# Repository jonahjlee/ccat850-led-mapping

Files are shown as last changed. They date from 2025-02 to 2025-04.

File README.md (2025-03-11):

# ccat850-led-mapping
CAD files for CCAT 850GHz LED mapping array PCB &amp; peripherals

This project contains various cad files relating to hardware required to perform LED mapping for CCAT's 850GHz module.
This project includes the following directories:
- ``led_mapper_850``
  - The defining the PCB for one rhombus of the LED mapper array. Contains the KiCAD project and some Python programs used to automate the LED/via/track layout.
- ``multiplexer`` - NO LONGER USED
  - The cable splitter used between the Arduino shield and the mapper array. Splits the inputs into 13 parallel 24-pin connectors. Since the PCB has been updated to use a single connector, this is no longer relevant to the project.
- ``collimator``
  - SOLIDWORKS CAD files for the collimator, which mounts to the array and nests each LED such that light is funneled one-to-one with the feedhorns. The old collimator CAD model can be found in [this onshape project](https://cad.onshape.com/documents/4a9874995d3b4039a34f4491/w/a61d1c1f9ee3ea8193c6d7eb/e/afbea4677e4648f6492246a2).

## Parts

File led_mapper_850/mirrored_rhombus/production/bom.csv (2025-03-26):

Designator | Footprint | Quantity | Value | LCSC Part #
D1, D10, D100, D1000, D1001, D1002, D1003, D1004, D1005, D1006, D1007, D1008, D1009, D101, D1010, D1011, D1012, D1013, D1014, D1015, D1016, D1017, D1018, D1019, D102, D1020, D1021, D1022, D1023, D1024, D1025, D1026, D1027, D1028, D1029, D103, D1030, D1031, D1032, D1033, D1034, D1035, D1036, D1037, D1038, D1039, D104, D1040, D1041, D1042, D1043, D1044, D1045, D1046, D1047, D1048, D1049, D105, D1050, D1051, D1052, D1053, D1054, D1055, D1056, D1057, D1058, D1059, D106, D1060, D1061, D1062, D1063, D1064, D1065, D1066, D1067, D1068, D1069, D107, D1070, D1071, D1072, D1073, D1074, D1075, D1076, D1077, D1078, D1079, D108, D1080, D1081, D1082, D1083, D1084, D1085, D1086, D1087, D1088, D1089, D109, D1090, D1091, D1092, D1093, D1094, D1095, D1096, D1097, D1098, D1099, D11, D110, D1100, D1101, D1102, D1103, D1104, D1105, D1106, D1107, D1108, D1109, D111, D1110, D1111, D1112, D1113, D1114, D1115, D1116, D1117, D1118, D1119, D112, D1120, D1121, D1122, D1123, D1124, D1125, D1126, D1127, D1128, D1129, D113, D1130, D1131, D1132, D1133, D1134, D1135, D1136, D1137, D1138, D1139, D114, D1140, D1141, D1142, D1143, D1144, D1145, D1146, D1147, D1148, D1149, D115, D1150, D1151, D1152, D1153, D1154, D1155, D1156, D1157, D1158, D1159, D116, D1160, D1161, D1162, D1163, D1164, D1165, D1166, D1167, D1168, D1169, D117, D1170, D1171, D1172, D1173, D1174, D1175, D1176, D1177, D1178 | 0201 | 200 | LED | C3646923
D1179, D118, D1180, D1181, D1182, D1183, D1184, D1185, D1186, D1187, D1188, D1189, D119, D1190, D1191, D1192, D1193, D1194, D1195, D1196, D1197, D1198, D1199, D12, D120, D1200, D1201, D1202, D1203, D1204, D1205, D1206, D1207, D1208, D1209, D121, D1210, D1211, D1212, D1213, D1214, D1215, D1216, D1217, D1218, D1219, D122, D1220, D1221, D1222, D1223, D1224, D1225, D1226, D1227, D1228, D1229, D123, D1230, D1231, D1232, D1233, D1234, D1235, D1236, D1237, D1238, D1239, D124, D1240, D1241, D1242, D1243, D1244, D1245, D1246, D1247, D1248, D1249, D125, D1250, D1251, D1252, D1253, D1254, D1255, D1256, D1257, D1258, D1259, D126, D1260, D1261, D1262, D1263, D1264, D1265, D1266, D1267, D1268, D1269, D127, D1270, D1271, D1272, D1273, D1274, D1275, D1276, D1277, D1278, D1279, D128, D1280, D1281, D1282, D1283, D1284, D1285, D1286, D1287, D1288, D1289, D129, D1290, D1291, D1292, D1293, D1294, D1295, D1296, D1297, D1298, D1299, D13, D130, D1300, D1301, D1302, D1303, D1304, D1305, D1306, D1307, D1308, D1309, D131, D1310, D1311, D1312, D1313, D1314, D1315, D1316, D1317, D1318, D1319, D132, D1320, D1321, D1322, D1323, D1324, D1325, D1326, D1327, D1328, D1329, D133, D1330, D1331, D1332, D1333, D1334, D1335, D1336, D1337, D1338, D1339, D134, D1340, D1341, D1342, D1343, D1344, D1345, D1346, D1347, D1348, D1349, D135, D1350, D1351, D1352, D1353, D1354, D1355, D1356, D1357, D1358 | 0201 | 200 | LED | C3646923
D1359, D136, D1360, D1361, D1362, D1363, D1364, D1365, D1366, D1367, D1368, D1369, D137, D1370, D1371, D1372, D1373, D1374, D1375, D1376, D1377, D1378, D1379, D138, D1380, D1381, D1382, D1383, D1384, D1385, D1386, D1387, D1388, D1389, D139, D1390, D1391, D1392, D1393, D1394, D1395, D1396, D1397, D1398, D1399, D14, D140, D1400, D1401, D1402, D1403, D1404, D1405, D1406, D1407, D1408, D1409, D141, D1410, D1411, D1412, D1413, D1414, D1415, D1416, D1417, D1418, D1419, D142, D1420, D1421, D1422, D1423, D1424, D1425, D1426, D1427, D1428, D1429, D143, D1430, D1431, D1432, D1433, D1434, D1435, D1436, D1437, D1438, D1439, D144, D1440, D1441, D1442, D1443, D1444, D1445, D1446, D1447, D1448, D1449, D145, D1450, D1451, D1452, D1453, D1454, D1455, D1456, D1457, D1458, D1459, D146, D1460, D1461, D1462, D1463, D1464, D1465, D1466, D1467, D1468, D1469, D147, D1470, D1471, D1472, D1473, D1474, D1475, D1476, D1477, D1478, D1479, D148, D1480, D1481, D1482, D1483, D1484, D1485, D1486, D1487, D1488, D1489, D149, D1490, D1491, D1492, D1493, D1494, D1495, D1496, D1497, D1498, D1499, D15, D150, D1500, D1501, D1502, D1503, D1504, D1505, D1506, D1507, D1508, D1509, D151, D1510, D1511, D1512, D1513, D1514, D1515, D1516, D1517, D1518, D1519, D152, D1520, D1521, D1522, D1523, D1524, D1525, D1526, D1527, D1528, D1529, D153, D1530, D1531, D1532, D1533, D1534, D1535, D1536, D1537, D1538 | 0201 | 200 | LED | C3646923
D1539, D154, D1540, D1541, D1542, D1543, D1544, D1545, D1546, D1547, D1548, D1549, D155, D1550, D1551, D1552, D1553, D1554, D1555, D1556, D1557, D1558, D1559, D156, D1560, D1561, D1562, D1563, D1564, D1565, D1566, D1567, D1568, D1569, D157, D1570, D1571, D1572, D1573, D1574, D1575, D1576, D1577, D1578, D1579, D158, D1580, D1581, D1582, D1583, D1584, D1585, D1586, D1587, D1588, D1589, D159, D1590, D1591, D1592, D1593, D1594, D1595, D1596, D1597, D1598, D1599, D16, D160, D1600, D1601, D1602, D1603, D1604, D1605, D1606, D1607, D1608, D1609, D161, D1610, D1611, D1612, D1613, D1614, D1615, D1616, D1617, D1618, D1619, D162, D1620, D1621, D1622, D1623, D1624, D1625, D1626, D1627, D1628, D1629, D163, D1630, D1631, D1632, D1633, D1634, D1635, D1636, D1637, D1638, D1639, D164, D1640, D1641, D1642, D1643, D1644, D1645, D1646, D1647, D1648, D1649, D165, D1650, D1651, D1652, D1653, D1654, D1655, D1656, D1657, D1658, D1659, D166, D1660, D1661, D1662, D1663, D1664, D1665, D1666, D1667, D1668, D1669, D167, D1670, D1671, D1672, D1673, D1674, D1675, D1676, D1677, D1678, D1679, D168, D1680, D1681, D1682, D1683, D1684, D1685, D1686, D1687, D1688, D1689, D169, D1690, D1691, D1692, D1693, D1694, D1695, D1696, D1697, D1698, D1699, D17, D170, D1700, D1701, D1702, D1703, D1704, D1705, D1706, D1707, D1708, D1709, D171, D1710, D1711, D1712, D1713, D1714, D1715, D1716, D1717, D1718 | 0201 | 200 | LED | C3646923
D1719, D172, D1720, D1721, D1722, D1723, D1724, D1725, D1726, D1727, D1728, D1729, D173, D1730, D1731, D1732, D1733, D1734, D1735, D1736, D1737, D1738, D1739, D174, D1740, D1741, D1742, D1743, D1744, D1745, D1746, D1747, D1748, D1749, D175, D1750, D1751, D1752, D1753, D1754, D1755, D1756, D1757, D1758, D1759, D176, D1760, D1761, D1762, D1763, D1764, D1765, D1766, D1767, D1768, D1769, D177, D1770, D1771, D1772, D1773, D1774, D1775, D1776, D1777, D1778, D1779, D178, D1780, D1781, D1782, D1783, D1784, D1785, D1786, D1787, D1788, D1789, D179, D1790, D1791, D1792, D1793, D1794, D1795, D1796, D1797, D1798, D1799, D18, D180, D1800, D1801, D1802, D1803, D1804, D1805, D1806, D1807, D1808, D1809, D181, D1810, D1811, D1812, D1813, D1814, D1815, D1816, D1817, D1818, D1819, D182, D1820, D1821, D1822, D1823, D1824, D1825, D1826, D1827, D1828, D1829, D183, D1830, D1831, D1832, D1833, D1834, D1835, D1836, D1837, D1838, D1839, D184, D1840, D1841, D1842, D1843, D1844, D1845, D1846, D1847, D1848, D1849, D185, D1850, D1851, D1852, D1853, D1854, D1855, D1856, D1857, D1858, D1859, D186, D1860, D1861, D1862, D1863, D1864, D1865, D1866, D1867, D1868, D1869, D187, D1870, D1871, D1872, D1873, D1874, D1875, D1876, D1877, D1878, D1879, D188, D1880, D1881, D1882, D1883, D1884, D1885, D1886, D1887, D1888, D1889, D189, D1890, D1891, D1892, D1893, D1894, D1895, D1896, D1897, D1898, D1899 | 0201 | 200 | LED | C3646923
D19, D190, D1900, D1901, D1902, D1903, D1904, D1905, D1906, D1907, D1908, D1909, D191, D1910, D1911, D1912, D1913, D1914, D1915, D1916, D1917, D1918, D1919, D192, D1920, D1921, D1922, D1923, D1924, D1925, D1926, D1927, D1928, D1929, D193, D1930, D1931, D1932, D1933, D1934, D1935, D1936, D1937, D1938, D1939, D194, D1940, D1941, D1942, D1943, D1944, D1945, D1946, D1947, D1948, D1949, D195, D1950, D1951, D1952, D1953, D1954, D1955, D1956, D1957, D1958, D1959, D196, D1960, D1961, D1962, D1963, D1964, D1965, D1966, D1967, D1968, D1969, D197, D1970, D1971, D1972, D1973, D1974, D1975, D1976, D1977, D1978, D1979, D198, D1980, D1981, D1982, D1983, D1984, D1985, D1986, D1987, D1988, D1989, D199, D1990, D1991, D1992, D1993, D1994, D1995, D1996, D1997, D1998, D1999, D2, D20, D200, D2000, D2001, D2002, D2003, D2004, D2005, D2006, D2007, D2008, D2009, D201, D2010, D2011, D2012, D2013, D2014, D2015, D2016, D2017, D2018, D2019, D202, D2020, D2021, D2022, D2023, D2024, D2025, D2026, D2027, D2028, D2029, D203, D2030, D2031, D2032, D2033, D2034, D2035, D2036, D2037, D2038, D2039, D204, D2040, D2041, D2042, D2043, D2044, D2045, D2046, D2047, D2048, D2049, D205, D2050, D2051, D2052, D2053, D2054, D2055, D2056, D2057, D2058, D2059, D206, D2060, D2061, D2062, D2063, D2064, D2065, D2066, D2067, D2068, D2069, D207, D2070, D2071, D2072, D2073, D2074, D2075, D2076, D2077, D2078 | 0201 | 200 | LED | C3646923
D2079, D208, D2080, D2081, D2082, D2083, D2084, D2085, D2086, D2087, D2088, D2089, D209, D2090, D2091, D2092, D2093, D2094, D2095, D2096, D2097, D2098, D2099, D21, D210, D2100, D2101, D2102, D2103, D2104, D2105, D2106, D2107, D2108, D2109, D211, D2110, D2111, D2112, D2113, D2114, D2115, D2116, D212, D213, D214, D215, D216, D217, D218, D219, D22, D220, D221, D222, D223, D224, D225, D226, D227, D228, D229, D23, D230, D231, D232, D233, D234, D235, D236, D237, D238, D239, D24, D240, D241, D242, D243, D244, D245, D246, D247, D248, D249, D25, D250, D251, D252, D253, D254, D255, D256, D257, D258, D259, D26, D260, D261, D262, D263, D264, D265, D266, D267, D268, D269, D27, D270, D271, D272, D273, D274, D275, D276, D277, D278, D279, D28, D280, D281, D282, D283, D284, D285, D286, D287, D288, D289, D29, D290, D291, D292, D293, D294, D295, D296, D297, D298, D299, D3, D30, D300, D301, D302, D303, D304, D305, D306, D307, D308, D309, D31, D310, D311, D312, D313, D314, D315, D316, D317, D318, D319, D32, D320, D321, D322, D323, D324, D325, D326, D327, D328, D329, D33, D330, D331, D332, D333, D334, D335, D336, D337, D338, D339, D34, D340, D341, D342, D343, D344, D345, D346, D347, D348, D349, D35, D350, D351, D352, D353 | 0201 | 200 | LED | C3646923
D354, D355, D356, D357, D358, D359, D36, D360, D361, D362, D363, D364, D365, D366, D367, D368, D369, D37, D370, D371, D372, D373, D374, D375, D376, D377, D378, D379, D38, D380, D381, D382, D383, D384, D385, D386, D387, D388, D389, D39, D390, D391, D392, D393, D394, D395, D396, D397, D398, D399, D4, D40, D400, D401, D402, D403, D404, D405, D406, D407, D408, D409, D41, D410, D411, D412, D413, D414, D415, D416, D417, D418, D419, D42, D420, D421, D422, D423, D424, D425, D426, D427, D428, D429, D43, D430, D431, D432, D433, D434, D435, D436, D437, D438, D439, D44, D440, D441, D442, D443, D444, D445, D446, D447, D448, D449, D45, D450, D451, D452, D453, D454, D455, D456, D457, D458, D459, D46, D460, D461, D462, D463, D464, D465, D466, D467, D468, D469, D47, D470, D471, D472, D473, D474, D475, D476, D477, D478, D479, D48, D480, D481, D482, D483, D484, D485, D486, D487, D488, D489, D49, D490, D491, D492, D493, D494, D495, D496, D497, D498, D499, D5, D50, D500, D501, D502, D503, D504, D505, D506, D507, D508, D509, D51, D510, D511, D512, D513, D514, D515, D516, D517, D518, D519, D52, D520, D521, D522, D523, D524, D525, D526, D527, D528, D529, D53, D530, D531, D532, D533 | 0201 | 200 | LED | C3646923
D534, D535, D536, D537, D538, D539, D54, D540, D541, D542, D543, D544, D545, D546, D547, D548, D549, D55, D550, D551, D552, D553, D554, D555, D556, D557, D558, D559, D56, D560, D561, D562, D563, D564, D565, D566, D567, D568, D569, D57, D570, D571, D572, D573, D574, D575, D576, D577, D578, D579, D58, D580, D581, D582, D583, D584, D585, D586, D587, D588, D589, D59, D590, D591, D592, D593, D594, D595, D596, D597, D598, D599, D6, D60, D600, D601, D602, D603, D604, D605, D606, D607, D608, D609, D61, D610, D611, D612, D613, D614, D615, D616, D617, D618, D619, D62, D620, D621, D622, D623, D624, D625, D626, D627, D628, D629, D63, D630, D631, D632, D633, D634, D635, D636, D637, D638, D639, D64, D640, D641, D642, D643, D644, D645, D646, D647, D648, D649, D65, D650, D651, D652, D653, D654, D655, D656, D657, D658, D659, D66, D660, D661, D662, D663, D664, D665, D666, D667, D668, D669, D67, D670, D671, D672, D673, D674, D675, D676, D677, D678, D679, D68, D680, D681, D682, D683, D684, D685, D686, D687, D688, D689, D69, D690, D691, D692, D693, D694, D695, D696, D697, D698, D699, D7, D70, D700, D701, D702, D703, D704, D705, D706, D707, D708, D709, D71, D710, D711, D712, D713 | 0201 | 200 | LED | C3646923
D714, D715, D716, D717, D718, D719, D72, D720, D721, D722, D723, D724, D725, D726, D727, D728, D729, D73, D730, D731, D732, D733, D734, D735, D736, D737, D738, D739, D74, D740, D741, D742, D743, D744, D745, D746, D747, D748, D749, D75, D750, D751, D752, D753, D754, D755, D756, D757, D758, D759, D76, D760, D761, D762, D763, D764, D765, D766, D767, D768, D769, D77, D770, D771, D772, D773, D774, D775, D776, D777, D778, D779, D78, D780, D781, D782, D783, D784, D785, D786, D787, D788, D789, D79, D790, D791, D792, D793, D794, D795, D796, D797, D798, D799, D8, D80, D800, D801, D802, D803, D804, D805, D806, D807, D808, D809, D81, D810, D811, D812, D813, D814, D815, D816, D817, D818, D819, D82, D820, D821, D822, D823, D824, D825, D826, D827, D828, D829, D83, D830, D831, D832, D833, D834, D835, D836, D837, D838, D839, D84, D840, D841, D842, D843, D844, D845, D846, D847, D848, D849, D85, D850, D851, D852, D853, D854, D855, D856, D857, D858, D859, D86, D860, D861, D862, D863, D864, D865, D866, D867, D868, D869, D87, D870, D871, D872, D873, D874, D875, D876, D877, D878, D879, D88, D880, D881, D882, D883, D884, D885, D886, D887, D888, D889, D89, D890, D891, D892, D893, D894 | 0201 | 200 | LED | C3646923
D895, D896, D897, D898, D899, D9, D90, D900, D901, D902, D903, D904, D905, D906, D907, D908, D909, D91, D910, D911, D912, D913, D914, D915, D916, D917, D918, D919, D92, D920, D921, D922, D923, D924, D925, D926, D927, D928, D929, D93, D930, D931, D932, D933, D934, D935, D936, D937, D938, D939, D94, D940, D941, D942, D943, D944, D945, D946, D947, D948, D949, D95, D950, D951, D952, D953, D954, D955, D956, D957, D958, D959, D96, D960, D961, D962, D963, D964, D965, D966, D967, D968, D969, D97, D970, D971, D972, D973, D974, D975, D976, D977, D978, D979, D98, D980, D981, D982, D983, D984, D985, D986, D987, D988, D989, D99, D990, D991, D992, D993, D994, D995, D996, D997, D998, D999 | 0201 | 116 | LED | C3646923
J1 | PinSocket_2x12_P2.54mm_Vertical_SMD_custom | 1 | Conn_02x12_Top_Bottom | C19268781

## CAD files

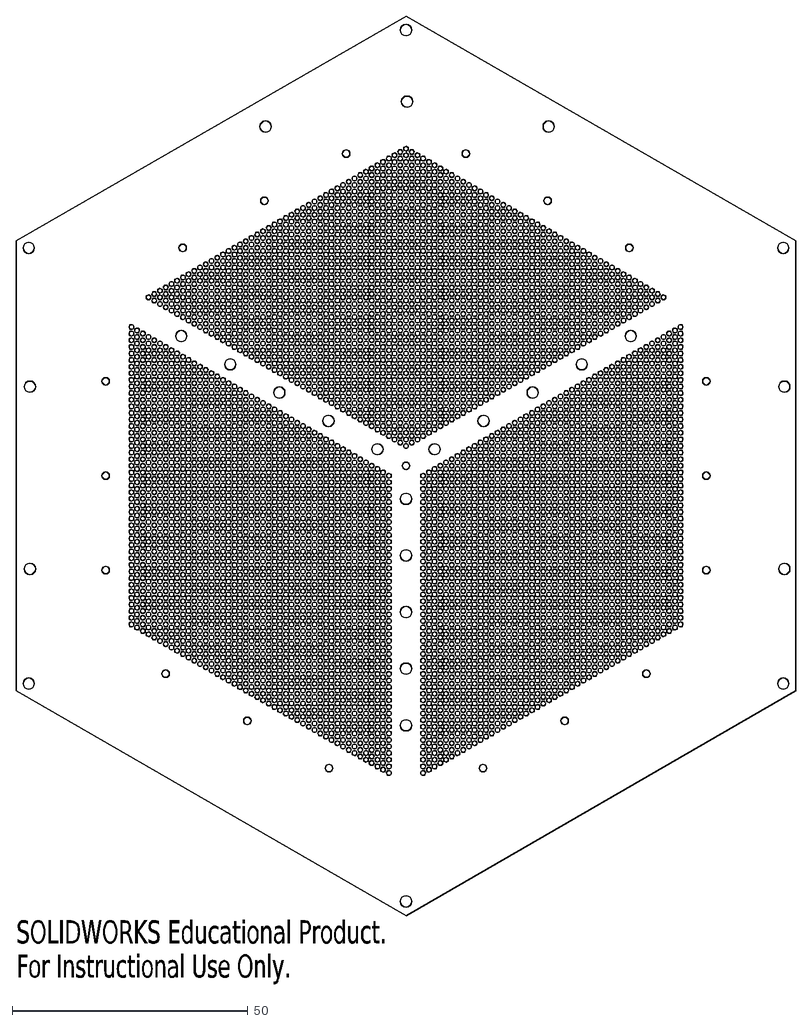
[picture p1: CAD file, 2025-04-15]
collimator/850_ghz_collimator_topface.DXF
SOLIDWORKS Educational Product.
For Instructional Use Only.

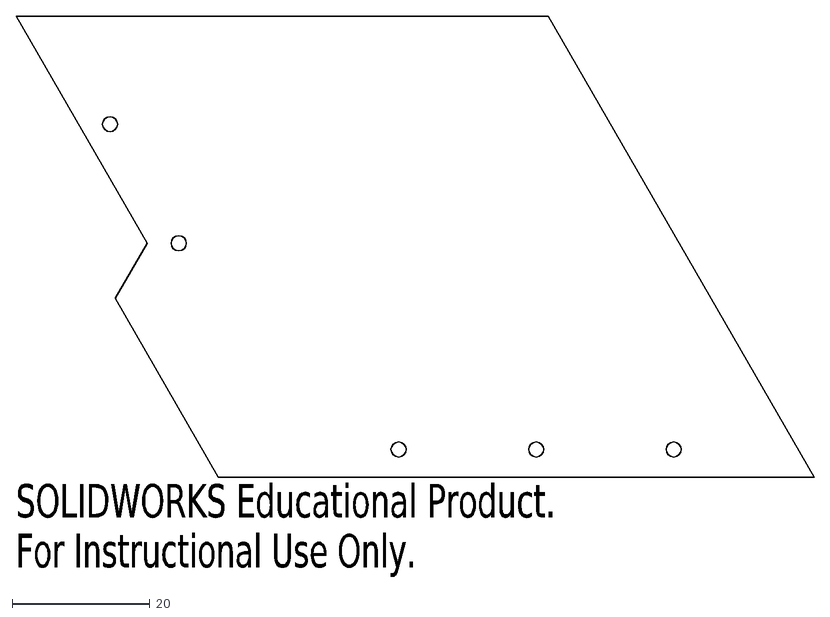
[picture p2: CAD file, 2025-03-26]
led_mapper_850/mirrored_rhombus/board_outline_2.2mmholes_mirrored.DXF
SOLIDWORKS Educational Product.
For Instructional Use Only.

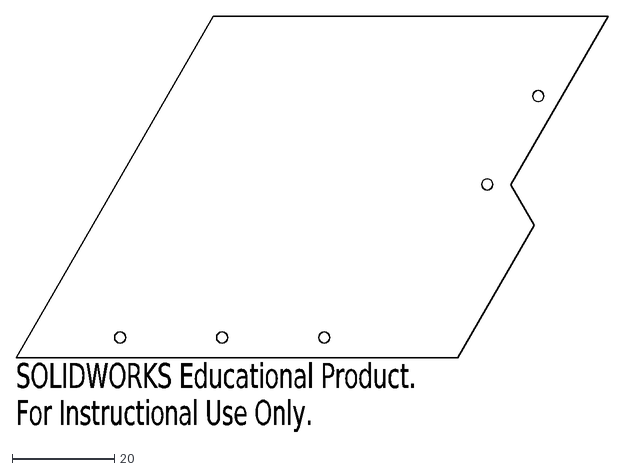
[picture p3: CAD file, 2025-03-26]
led_mapper_850/rhombus/board_outline_2.2mmholes.DXF
SOLIDWORKS Educational Product.
For Instructional Use Only.

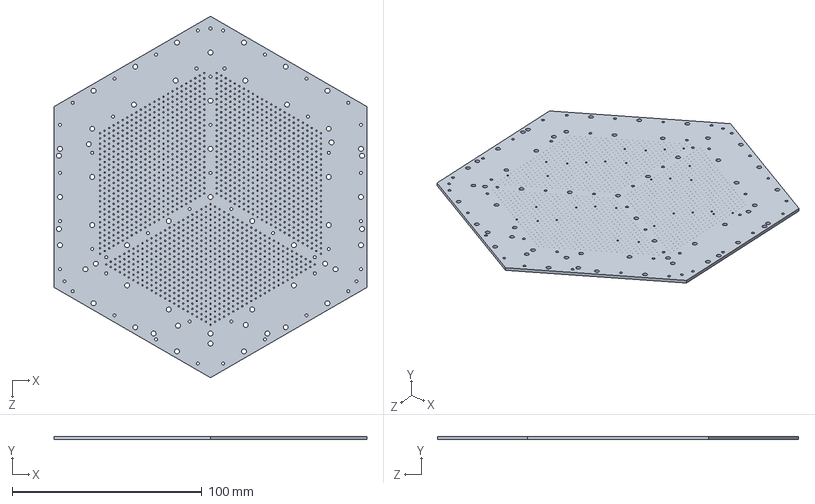
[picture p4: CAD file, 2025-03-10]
collimator/280_ghz_collimator_2.SLDPRT
165.1 x 1.59 x 190.6 mm

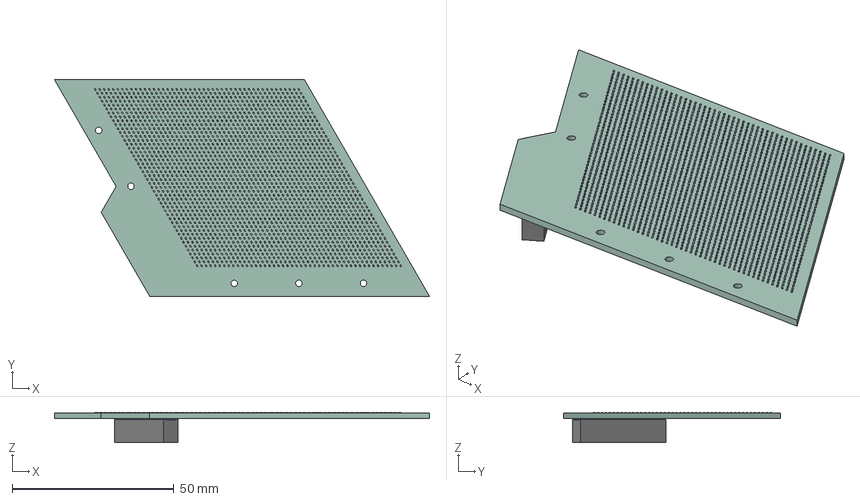
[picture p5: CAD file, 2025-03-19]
led_mapper_850/mirrored_rhombus/led_mapper_850_mirrored_v2.step
116.0 x 67.0 x 9.37 mm
LED_0201_0603Metric x 2116
PinSocket_2x12_P2.54mm_Vertical_SMD
led_mapper_850_mirrored_PCB

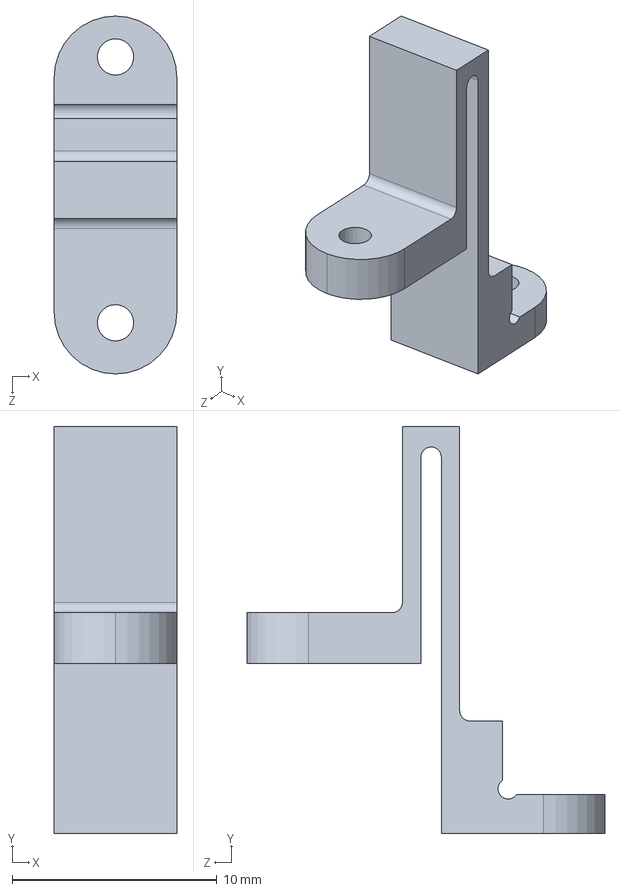
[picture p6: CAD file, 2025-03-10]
collimator/thermal_flex_outer_202502.SLDPRT
6.00 x 19.9 x 17.5 mm

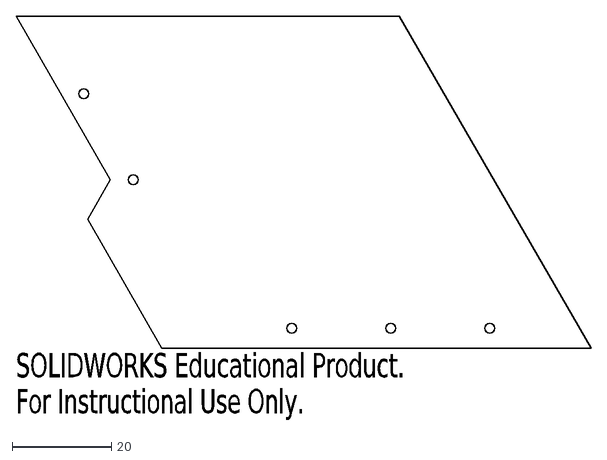
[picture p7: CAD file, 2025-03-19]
led_mapper_850/mirrored_rhombus/board_outline_2mmholes_mirrored_v2.DXF
SOLIDWORKS Educational Product.
For Instructional Use Only.

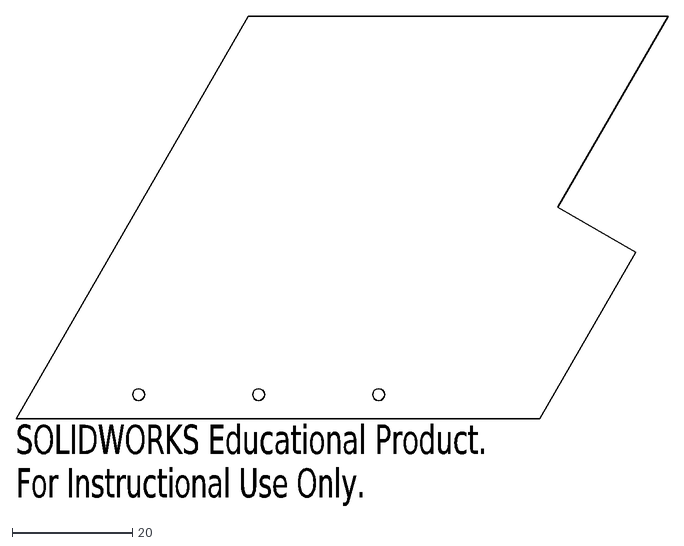
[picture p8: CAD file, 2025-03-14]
led_mapper_850/rhombus/board_outline_2mmholes_v4.DXF
SOLIDWORKS Educational Product.
For Instructional Use Only.

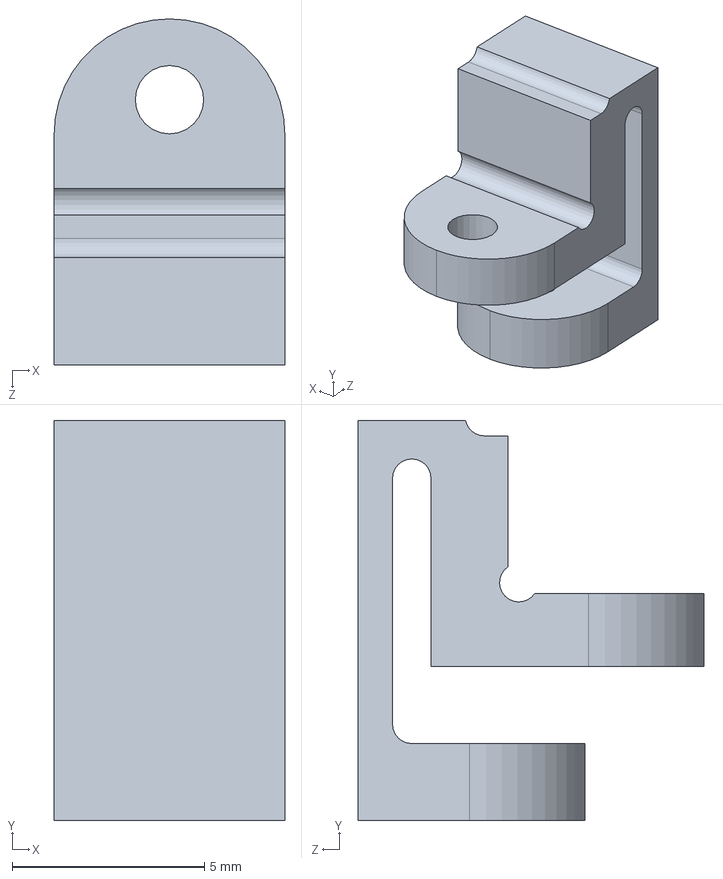
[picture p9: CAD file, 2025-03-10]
collimator/thermal_flex_inner_202501.SLDPRT
6.00 x 10.4 x 9.00 mm

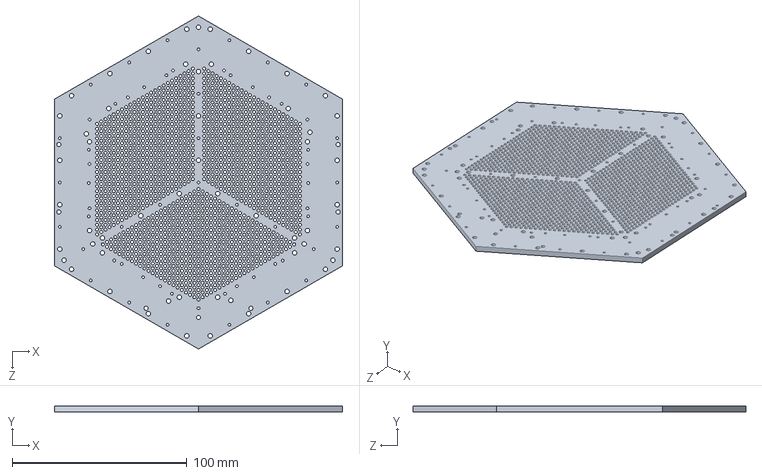
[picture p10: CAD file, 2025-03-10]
collimator/280_ghz_collimator.SLDPRT
165.1 x 3.17 x 190.6 mm

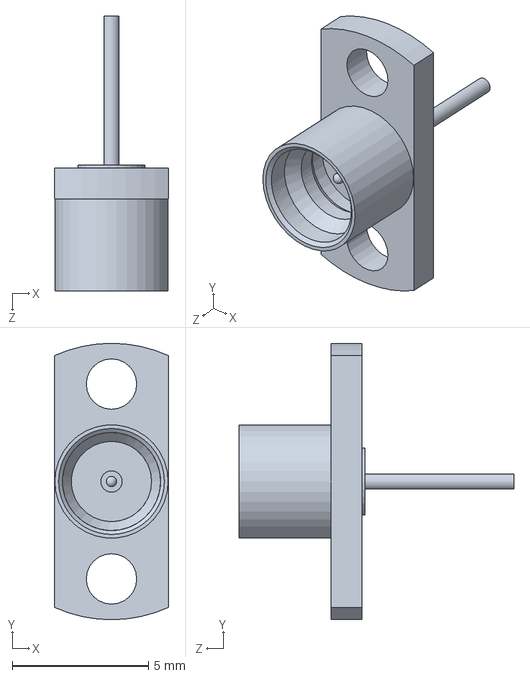
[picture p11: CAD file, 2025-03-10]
collimator/SMP_Connector.SLDPRT
4.19 x 10.2 x 10.1 mm

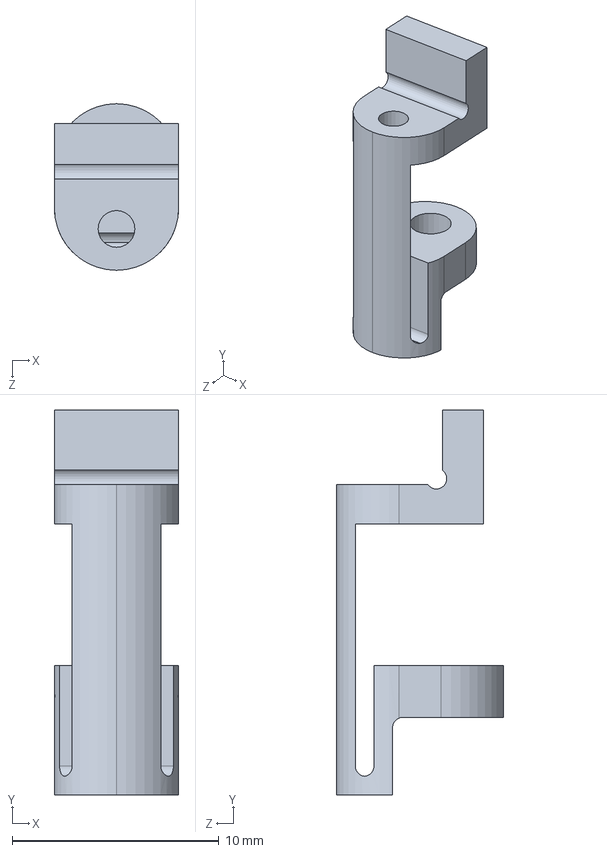
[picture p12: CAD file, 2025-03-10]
collimator/thermal_flex_inner_v2_202502.SLDPRT
6.00 x 18.6 x 8.05 mm

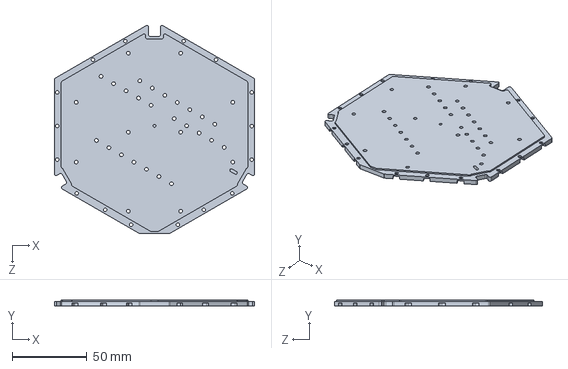
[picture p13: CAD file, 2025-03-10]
collimator/280_GHz_Si_Array_Final_Backplate_202502.SLDPRT
133.7 x 4.00 x 139.2 mm

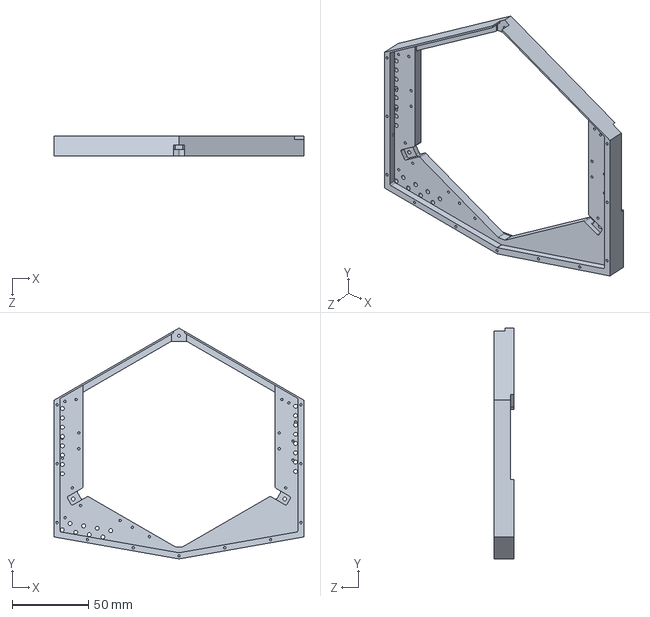
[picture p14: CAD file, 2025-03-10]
collimator/CCAT_850GHz_si_array_mount_202502.SLDPRT
163.9 x 151.4 x 12.8 mm

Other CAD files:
led_mapper_850/rhombus/led_mapper_850_v6.step
collimator/SC5323_3D.step
collimator/CCAT_850GHz_si_array_mount_202501.SLDPRT
collimator/280_GHz_Si_Array_Final_Backplate_08112022.SLDPRT
collimator/rhombus_edgecuts_v1.SLDDRW
collimator/thermal_flex_outer_202501.SLDPRT
led_mapper_850/mirrored_rhombus/board_outline_2mmholes_mirrored.DXF

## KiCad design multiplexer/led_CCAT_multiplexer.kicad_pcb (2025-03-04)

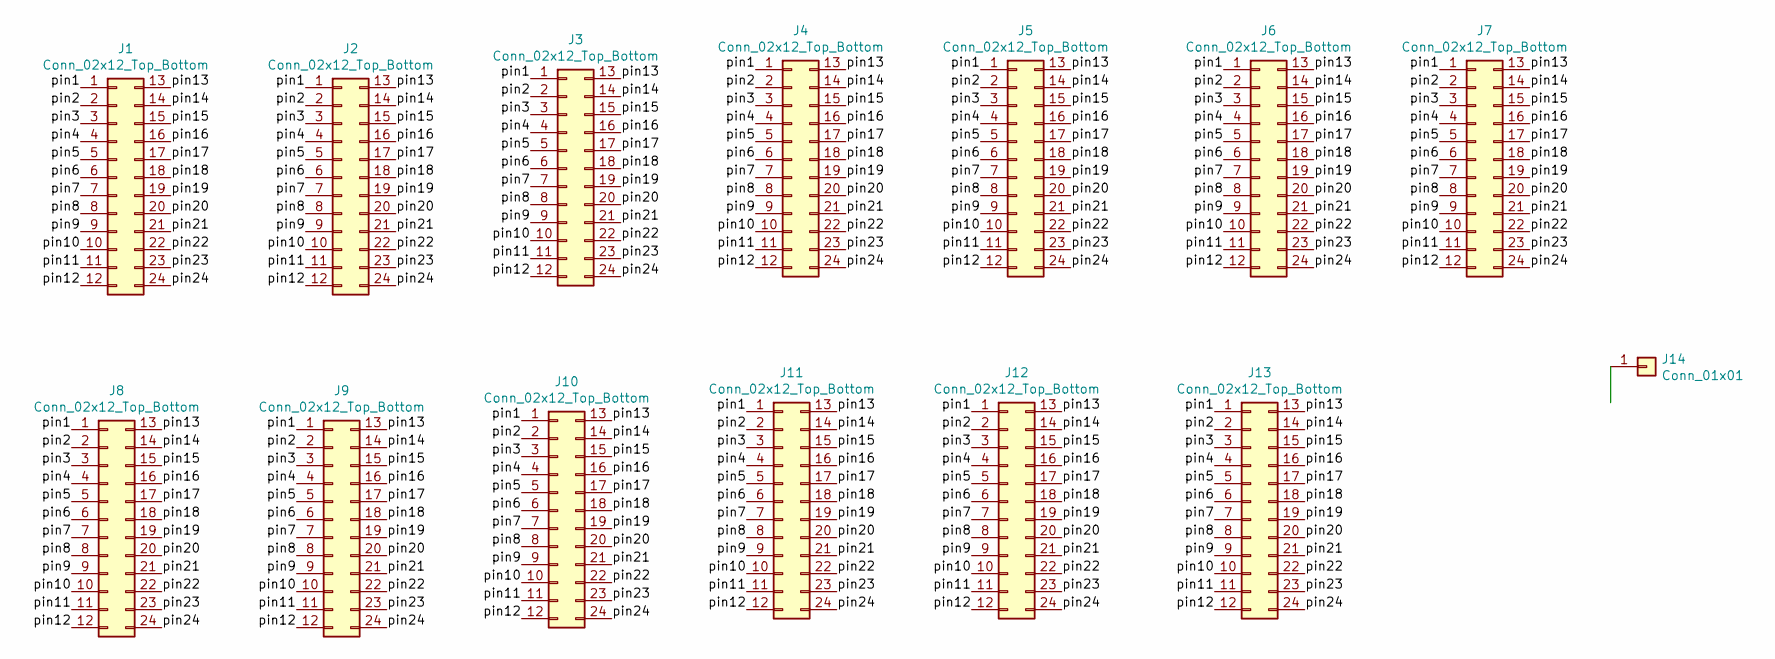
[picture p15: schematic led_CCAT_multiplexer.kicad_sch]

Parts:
J1, J2, J3, J4, J5, J6, J7, J8, J9, J10, J11, J12, J13: Conn_02x12_Top_Bottom; PinSocket_2x12_P2.54mm_Vertical
J14: Conn_01x01; TestPoint_Pad_1.0x1.0mm

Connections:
/pin1: J1.1, J2.1, J3.1, J4.1, J5.1, J6.1, J7.1, J8.1, J9.1, J10.1, J11.1, J12.1, J13.1, J14.1
/pin2: J1.2, J2.2, J3.2, J4.2, J5.2, J6.2, J7.2, J8.2, J9.2, J10.2, J11.2, J12.2, J13.2, J14.2
/pin3: J1.3, J2.3, J3.3, J4.3, J5.3, J6.3, J7.3, J8.3, J9.3, J10.3, J11.3, J12.3, J13.3, J14.3
/pin4: J1.4, J2.4, J3.4, J4.4, J5.4, J6.4, J7.4, J8.4, J9.4, J10.4, J11.4, J12.4, J13.4, J14.4
/pin5: J1.5, J2.5, J3.5, J4.5, J5.5, J6.5, J7.5, J8.5, J9.5, J10.5, J11.5, J12.5, J13.5, J14.5
/pin6: J1.6, J2.6, J3.6, J4.6, J5.6, J6.6, J7.6, J8.6, J9.6, J10.6, J11.6, J12.6, J13.6, J14.6
/pin7: J1.7, J2.7, J3.7, J4.7, J5.7, J6.7, J7.7, J8.7, J9.7, J10.7, J11.7, J12.7, J13.7, J14.7
/pin8: J1.8, J2.8, J3.8, J4.8, J5.8, J6.8, J7.8, J8.8, J9.8, J10.8, J11.8, J12.8, J13.8, J14.8
/pin9: J1.9, J2.9, J3.9, J4.9, J5.9, J6.9, J7.9, J8.9, J9.9, J10.9, J11.9, J12.9, J13.9, J14.9
/pin10: J1.10, J2.10, J3.10, J4.10, J5.10, J6.10, J7.10, J8.10, J9.10, J10.10, J11.10, J12.10, J13.10, J14.10
/pin11: J1.11, J2.11, J3.11, J4.11, J5.11, J6.11, J7.11, J8.11, J9.11, J10.11, J11.11, J12.11, J13.11, J14.11
/pin12: J1.12, J2.12, J3.12, J4.12, J5.12, J6.12, J7.12, J8.12, J9.12, J10.12, J11.12, J12.12, J13.12, J14.12
/pin13: J1.13, J2.13, J3.13, J4.13, J5.13, J6.13, J7.13, J8.13, J9.13, J10.13, J11.13, J12.13, J13.13, J14.14
/pin14: J1.14, J2.14, J3.14, J4.14, J5.14, J6.14, J7.14, J8.14, J9.14, J10.14, J11.14, J12.14, J13.14, J14.15
/pin15: J1.15, J2.15, J3.15, J4.15, J5.15, J6.15, J7.15, J8.15, J9.15, J10.15, J11.15, J12.15, J13.15, J14.16
/pin16: J1.16, J2.16, J3.16, J4.16, J5.16, J6.16, J7.16, J8.16, J9.16, J10.16, J11.16, J12.16, J13.16, J14.17
/pin17: J1.17, J2.17, J3.17, J4.17, J5.17, J6.17, J7.17, J8.17, J9.17, J10.17, J11.17, J12.17, J13.17, J14.18
/pin18: J1.18, J2.18, J3.18, J4.18, J5.18, J6.18, J7.18, J8.18, J9.18, J10.18, J11.18, J12.18, J13.18, J14.19
/pin19: J1.19, J2.19, J3.19, J4.19, J5.19, J6.19, J7.19, J8.19, J9.19, J10.19, J11.19, J12.19, J13.19, J14.20
/pin20: J1.20, J2.20, J3.20, J4.20, J5.20, J6.20, J7.20, J8.20, J9.20, J10.20, J11.20, J12.20, J13.20, J14.21
/pin21: J1.21, J2.21, J3.21, J4.21, J5.21, J6.21, J7.21, J8.21, J9.21, J10.21, J11.21, J12.21, J13.21, J14.22
/pin22: J1.22, J2.22, J3.22, J4.22, J5.22, J6.22, J7.22, J8.22, J9.22, J10.22, J11.22, J12.22, J13.22, J14.23
/pin23: J1.23, J2.23, J3.23, J4.23, J5.23, J6.23, J7.23, J8.23, J9.23, J10.23, J11.23, J12.23, J13.23, J14.24
/pin24: J1.24, J2.24, J3.24, J4.24, J5.24, J6.24, J7.24, J8.24, J9.24, J10.24, J11.24, J12.24, J13.24, J14.25
GND: J14.0 (PAD), J14.13

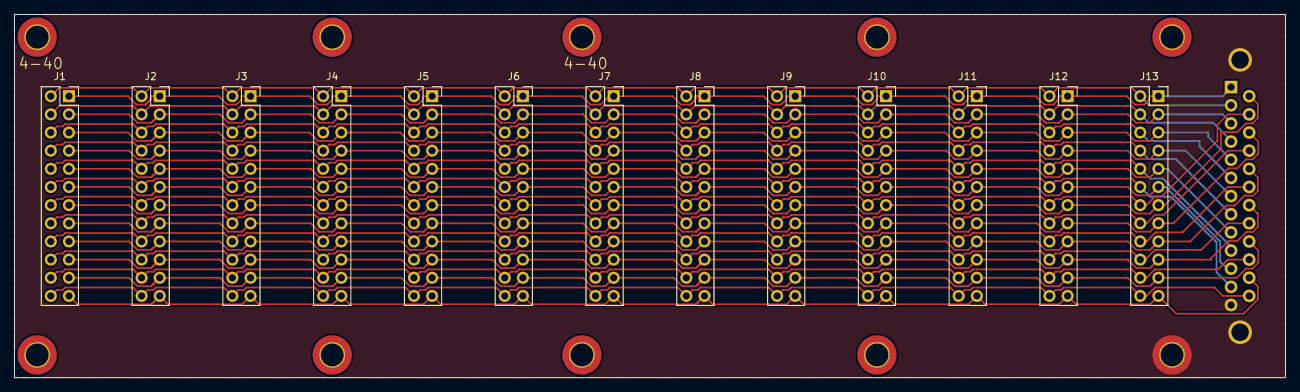
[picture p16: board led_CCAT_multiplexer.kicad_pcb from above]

Board: 2 copper layers, 177.8 x 50.8 mm, 14 parts (1 on the bottom side), 25 nets.

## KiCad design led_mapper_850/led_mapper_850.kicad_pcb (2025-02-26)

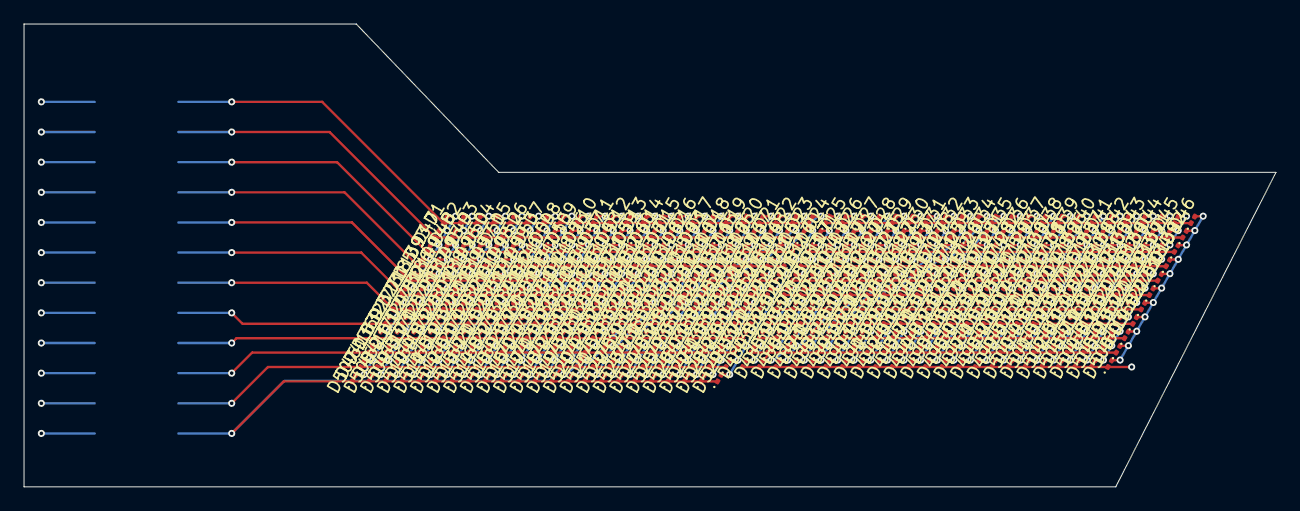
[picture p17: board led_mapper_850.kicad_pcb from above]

Board: 4 copper layers, 105.5 x 39.0 mm, 530 parts (1 on the bottom side), 24 nets.

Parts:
D1, D2, D3, D4, D5, D6, D7, D8, D9, D10, D11, D12, D13, D14, D15, D16, D17, D18, D19, D20, D21, D22, D23, D24, D25, D26, D27, D28, D29, D30, D31, D32, D33, D34, D35, D36, D37, D38, D39, D40, D41, D42, D43, D44, D45, D46, D47, D48, D49, D50, D51, D52, D53, D54, D55, D56, D57, D58, D59, D60, D61, D62, D63, D64, D65, D66, D67, D68, D69, D70, D71, D72, D73, D74, D75, D76, D77, D78, D79, D80, D81, D82, D83, D84, D85, D86, D87, D88, D89, D90, D91, D92, D93, D94, D95, D96, D97, D98, D99, D100, D101, D102, D103, D104, D105, D106, D107, D108, D109, D110, D111, D112, D113, D114, D115, D116, D117, D118, D119, D120, D121, D122, D123, D124, D125, D126, D127, D128, D129, D130, D131, D132, D133, D134, D135, D136, D137, D138, D139, D140, D141, D142, D143, D144, D145, D146, D147, D148, D149, D150, D151, D152, D153, D154, D155, D156, D157, D158, D159, D160, D161, D162, D163, D164, D165, D166, D167, D168, D169, D170, D171, D172, D173, D174, D175, D176, D177, D178, D179, D180, D181, D182, D183, D184, D185, D186, D187, D188, D189, D190, D191, D192, D193, D194, D195, D196, D197, D198, D199, D200, D201, D202, D203, D204, D205, D206, D207, D208, D209, D210, D211, D212, D213, D214, D215, D216, D217, D218, D219, D220, D221, D222, D223, D224, D225, D226, D227, D228, D229, D230, D231, D232, D233, D234, D235, D236, D237, D238, D239, D240, D241, D242, D243, D244, D245, D246, D247, D248, D249, D250, D251, D252, D253, D254, D255, D256, D257, D258, D259, D260, D261, D262, D263, D264, D265, D266, D267, D268, D269, D270, D271, D272, D273, D274, D275, D276, D277, D278, D279, D280, D281, D282, D283, D284, D285, D286, D287, D288, D289, D290, D291, D292, D293, D294, D295, D296, D297, D298, D299, D300, D301, D302, D303, D304, D305, D306, D307, D308, D309, D310, D311, D312, D313, D314, D315, D316, D317, D318, D319, D320, D321, D322, D323, D324, D325, D326, D327, D328, D329, D330, D331, D332, D333, D334, D335, D336, D337, D338, D339, D340, D341, D342, D343, D344, D345, D346, D347, D348, D349, D350, D351, D352, D353, D354, D355, D356, D357, D358, D359, D360, D361, D362, D363, D364, D365, D366, D367, D368, D369, D370, D371, D372, D373, D374, D375, D376, D377, D378, D379, D380, D381, D382, D383, D384, D385, D386, D387, D388, D389, D390, D391, D392, D393, D394, D395, D396, D397, D398, D399, D400, D401, D402, D403, D404, D405, D406, D407, D408, D409, D410, D411, D412, D413, D414, D415, D416, D417, D418, D419, D420, D421, D422, D423, D424, D425, D426, D427, D428, D429, D430, D431, D432, D433, D434, D435, D436, D437, D438, D439, D440, D441, D442, D443, D444, D445, D446, D447, D448, D449, D450, D451, D452, D453, D454, D455, D456, D457, D458, D459, D460, D461, D462, D463, D464, D465, D466, D467, D468, D469, D470, D471, D472, D473, D474, D475, D476, D477, D478, D479, D480, D481, D482, D483, D484, D485, D486, D487, D488, D489, D490, D491, D492, D493, D494, D495, D496, D497, D498, D499, D500, D501, D502, D503, D504, D505, D506, D507, D508, D509, D510, D511, D512, D513, D514, D515, D516, D517, D518, D519, D520, D521, D522, D523, D524, D525, D526, D527, D528, D529: LED; LED_0201_0603Metric
J1: Conn_02x12_Top_Bottom; PinSocket_2x12_P2.54mm_Vertical_SMD_custom

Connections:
/P01: D1.2 (A), D24.2 (A), D47.2 (A), D70.2 (A), D93.2 (A), D116.2 (A), D139.2 (A), D162.2 (A), D185.2 (A), D208.2 (A), D231.2 (A), D254.2 (A), D277.2 (A), D300.2 (A), D323.2 (A), D346.2 (A), D369.2 (A), D392.2 (A), D415.2 (A), D438.2 (A), D461.2 (A), D484.2 (A), D507.2 (A), J1.1
/P02: D2.2 (A), D25.2 (A), D48.2 (A), D71.2 (A), D94.2 (A), D117.2 (A), D140.2 (A), D163.2 (A), D186.2 (A), D209.2 (A), D232.2 (A), D255.2 (A), D278.2 (A), D301.2 (A), D324.2 (A), D347.2 (A), D370.2 (A), D393.2 (A), D416.2 (A), D439.2 (A), D462.2 (A), D484.1 (K), D485.1 (K), D486.1 (K), D487.1 (K), D488.1 (K), D489.1 (K), D490.1 (K), D491.1 (K), D492.1 (K), D493.1 (K), D494.1 (K), D495.1 (K), D496.1 (K), D497.1 (K), D498.1 (K), D499.1 (K), D500.1 (K), D501.1 (K), D502.1 (K), D503.1 (K), D504.1 (K), D505.1 (K), D506.1 (K), D508.2 (A), J1.2
/P03: D3.2 (A), D26.2 (A), D49.2 (A), D72.2 (A), D95.2 (A), D118.2 (A), D141.2 (A), D164.2 (A), D187.2 (A), D210.2 (A), D233.2 (A), D256.2 (A), D279.2 (A), D302.2 (A), D325.2 (A), D348.2 (A), D371.2 (A), D394.2 (A), D417.2 (A), D438.1 (K), D439.1 (K), D440.1 (K), D441.1 (K), D442.1 (K), D443.1 (K), D444.1 (K), D445.1 (K), D446.1 (K), D447.1 (K), D448.1 (K), D449.1 (K), D450.1 (K), D451.1 (K), D452.1 (K), D453.1 (K), D454.1 (K), D455.1 (K), D456.1 (K), D457.1 (K), D458.1 (K), D459.1 (K), D460.1 (K), D463.2 (A), D485.2 (A), D509.2 (A), J1.3
/P04: D4.2 (A), D27.2 (A), D50.2 (A), D73.2 (A), D96.2 (A), D119.2 (A), D142.2 (A), D165.2 (A), D188.2 (A), D211.2 (A), D234.2 (A), D257.2 (A), D280.2 (A), D303.2 (A), D326.2 (A), D349.2 (A), D372.2 (A), D392.1 (K), D393.1 (K), D394.1 (K), D395.1 (K), D396.1 (K), D397.1 (K), D398.1 (K), D399.1 (K), D400.1 (K), D401.1 (K), D402.1 (K), D403.1 (K), D404.1 (K), D405.1 (K), D406.1 (K), D407.1 (K), D408.1 (K), D409.1 (K), D410.1 (K), D411.1 (K), D412.1 (K), D413.1 (K), D414.1 (K), D418.2 (A), D440.2 (A), D464.2 (A), D486.2 (A), D510.2 (A), J1.4
/P05: D5.2 (A), D28.2 (A), D51.2 (A), D74.2 (A), D97.2 (A), D120.2 (A), D143.2 (A), D166.2 (A), D189.2 (A), D212.2 (A), D235.2 (A), D258.2 (A), D281.2 (A), D304.2 (A), D327.2 (A), D346.1 (K), D347.1 (K), D348.1 (K), D349.1 (K), D350.1 (K), D351.1 (K), D352.1 (K), D353.1 (K), D354.1 (K), D355.1 (K), D356.1 (K), D357.1 (K), D358.1 (K), D359.1 (K), D360.1 (K), D361.1 (K), D362.1 (K), D363.1 (K), D364.1 (K), D365.1 (K), D366.1 (K), D367.1 (K), D368.1 (K), D373.2 (A), D395.2 (A), D419.2 (A), D441.2 (A), D465.2 (A), D487.2 (A), D511.2 (A), J1.5
/P06: D6.2 (A), D29.2 (A), D52.2 (A), D75.2 (A), D98.2 (A), D121.2 (A), D144.2 (A), D167.2 (A), D190.2 (A), D213.2 (A), D236.2 (A), D259.2 (A), D282.2 (A), D300.1 (K), D301.1 (K), D302.1 (K), D303.1 (K), D304.1 (K), D305.1 (K), D306.1 (K), D307.1 (K), D308.1 (K), D309.1 (K), D310.1 (K), D311.1 (K), D312.1 (K), D313.1 (K), D314.1 (K), D315.1 (K), D316.1 (K), D317.1 (K), D318.1 (K), D319.1 (K), D320.1 (K), D321.1 (K), D322.1 (K), D328.2 (A), D350.2 (A), D374.2 (A), D396.2 (A), D420.2 (A), D442.2 (A), D466.2 (A), D488.2 (A), D512.2 (A), J1.6
/P07: D7.2 (A), D30.2 (A), D53.2 (A), D76.2 (A), D99.2 (A), D122.2 (A), D145.2 (A), D168.2 (A), D191.2 (A), D214.2 (A), D237.2 (A), D254.1 (K), D255.1 (K), D256.1 (K), D257.1 (K), D258.1 (K), D259.1 (K), D260.1 (K), D261.1 (K), D262.1 (K), D263.1 (K), D264.1 (K), D265.1 (K), D266.1 (K), D267.1 (K), D268.1 (K), D269.1 (K), D270.1 (K), D271.1 (K), D272.1 (K), D273.1 (K), D274.1 (K), D275.1 (K), D276.1 (K), D283.2 (A), D305.2 (A), D329.2 (A), D351.2 (A), D375.2 (A), D397.2 (A), D421.2 (A), D443.2 (A), D467.2 (A), D489.2 (A), D513.2 (A), J1.7
/P08: D8.2 (A), D31.2 (A), D54.2 (A), D77.2 (A), D100.2 (A), D123.2 (A), D146.2 (A), D169.2 (A), D192.2 (A), D208.1 (K), D209.1 (K), D210.1 (K), D211.1 (K), D212.1 (K), D213.1 (K), D214.1 (K), D215.1 (K), D216.1 (K), D217.1 (K), D218.1 (K), D219.1 (K), D220.1 (K), D221.1 (K), D222.1 (K), D223.1 (K), D224.1 (K), D225.1 (K), D226.1 (K), D227.1 (K), D228.1 (K), D229.1 (K), D230.1 (K), D238.2 (A), D260.2 (A), D284.2 (A), D306.2 (A), D330.2 (A), D352.2 (A), D376.2 (A), D398.2 (A), D422.2 (A), D444.2 (A), D468.2 (A), D490.2 (A), D514.2 (A), J1.8
/P09: D9.2 (A), D32.2 (A), D55.2 (A), D78.2 (A), D101.2 (A), D124.2 (A), D147.2 (A), D162.1 (K), D163.1 (K), D164.1 (K), D165.1 (K), D166.1 (K), D167.1 (K), D168.1 (K), D169.1 (K), D170.1 (K), D171.1 (K), D172.1 (K), D173.1 (K), D174.1 (K), D175.1 (K), D176.1 (K), D177.1 (K), D178.1 (K), D179.1 (K), D180.1 (K), D181.1 (K), D182.1 (K), D183.1 (K), D184.1 (K), D193.2 (A), D215.2 (A), D239.2 (A), D261.2 (A), D285.2 (A), D307.2 (A), D331.2 (A), D353.2 (A), D377.2 (A), D399.2 (A), D423.2 (A), D445.2 (A), D469.2 (A), D491.2 (A), D515.2 (A), J1.9
/P10: D10.2 (A), D33.2 (A), D56.2 (A), D79.2 (A), D102.2 (A), D116.1 (K), D117.1 (K), D118.1 (K), D119.1 (K), D120.1 (K), D121.1 (K), D122.1 (K), D123.1 (K), D124.1 (K), D125.1 (K), D126.1 (K), D127.1 (K), D128.1 (K), D129.1 (K), D130.1 (K), D131.1 (K), D132.1 (K), D133.1 (K), D134.1 (K), D135.1 (K), D136.1 (K), D137.1 (K), D138.1 (K), D148.2 (A), D170.2 (A), D194.2 (A), D216.2 (A), D240.2 (A), D262.2 (A), D286.2 (A), D308.2 (A), D332.2 (A), D354.2 (A), D378.2 (A), D400.2 (A), D424.2 (A), D446.2 (A), D470.2 (A), D492.2 (A), D516.2 (A), J1.10
/P11: D11.2 (A), D34.2 (A), D57.2 (A), D70.1 (K), D71.1 (K), D72.1 (K), D73.1 (K), D74.1 (K), D75.1 (K), D76.1 (K), D77.1 (K), D78.1 (K), D79.1 (K), D80.1 (K), D81.1 (K), D82.1 (K), D83.1 (K), D84.1 (K), D85.1 (K), D86.1 (K), D87.1 (K), D88.1 (K), D89.1 (K), D90.1 (K), D91.1 (K), D92.1 (K), D103.2 (A), D125.2 (A), D149.2 (A), D171.2 (A), D195.2 (A), D217.2 (A), D241.2 (A), D263.2 (A), D287.2 (A), D309.2 (A), D333.2 (A), D355.2 (A), D379.2 (A), D401.2 (A), D425.2 (A), D447.2 (A), D471.2 (A), D493.2 (A), D517.2 (A), J1.11
/P12: D12.2 (A), D24.1 (K), D25.1 (K), D26.1 (K), D27.1 (K), D28.1 (K), D29.1 (K), D30.1 (K), D31.1 (K), D32.1 (K), D33.1 (K), D34.1 (K), D35.1 (K), D36.1 (K), D37.1 (K), D38.1 (K), D39.1 (K), D40.1 (K), D41.1 (K), D42.1 (K), D43.1 (K), D44.1 (K), D45.1 (K), D46.1 (K), D58.2 (A), D80.2 (A), D104.2 (A), D126.2 (A), D150.2 (A), D172.2 (A), D196.2 (A), D218.2 (A), D242.2 (A), D264.2 (A), D288.2 (A), D310.2 (A), D334.2 (A), D356.2 (A), D380.2 (A), D402.2 (A), D426.2 (A), D448.2 (A), D472.2 (A), D494.2 (A), D518.2 (A), J1.12
/P13: D13.2 (A), D35.2 (A), D59.2 (A), D81.2 (A), D105.2 (A), D127.2 (A), D151.2 (A), D173.2 (A), D197.2 (A), D219.2 (A), D243.2 (A), D265.2 (A), D289.2 (A), D311.2 (A), D335.2 (A), D357.2 (A), D381.2 (A), D403.2 (A), D427.2 (A), D449.2 (A), D473.2 (A), D495.2 (A), D507.1 (K), D508.1 (K), D509.1 (K), D510.1 (K), D511.1 (K), D512.1 (K), D513.1 (K), D514.1 (K), D515.1 (K), D516.1 (K), D517.1 (K), D518.1 (K), D519.1 (K), D520.1 (K), D521.1 (K), D522.1 (K), D523.1 (K), D524.1 (K), D525.1 (K), D526.1 (K), D527.1 (K), D528.1 (K), D529.1 (K), J1.13
/P14: D14.2 (A), D36.2 (A), D60.2 (A), D82.2 (A), D106.2 (A), D128.2 (A), D152.2 (A), D174.2 (A), D198.2 (A), D220.2 (A), D244.2 (A), D266.2 (A), D290.2 (A), D312.2 (A), D336.2 (A), D358.2 (A), D382.2 (A), D404.2 (A), D428.2 (A), D450.2 (A), D461.1 (K), D462.1 (K), D463.1 (K), D464.1 (K), D465.1 (K), D466.1 (K), D467.1 (K), D468.1 (K), D469.1 (K), D470.1 (K), D471.1 (K), D472.1 (K), D473.1 (K), D474.1 (K), D475.1 (K), D476.1 (K), D477.1 (K), D478.1 (K), D479.1 (K), D480.1 (K), D481.1 (K), D482.1 (K), D483.1 (K), D496.2 (A), D519.2 (A), J1.14
/P15: D15.2 (A), D37.2 (A), D61.2 (A), D83.2 (A), D107.2 (A), D129.2 (A), D153.2 (A), D175.2 (A), D199.2 (A), D221.2 (A), D245.2 (A), D267.2 (A), D291.2 (A), D313.2 (A), D337.2 (A), D359.2 (A), D383.2 (A), D405.2 (A), D415.1 (K), D416.1 (K), D417.1 (K), D418.1 (K), D419.1 (K), D420.1 (K), D421.1 (K), D422.1 (K), D423.1 (K), D424.1 (K), D425.1 (K), D426.1 (K), D427.1 (K), D428.1 (K), D429.1 (K), D430.1 (K), D431.1 (K), D432.1 (K), D433.1 (K), D434.1 (K), D435.1 (K), D436.1 (K), D437.1 (K), D451.2 (A), D474.2 (A), D497.2 (A), D520.2 (A), J1.15
/P16: D16.2 (A), D38.2 (A), D62.2 (A), D84.2 (A), D108.2 (A), D130.2 (A), D154.2 (A), D176.2 (A), D200.2 (A), D222.2 (A), D246.2 (A), D268.2 (A), D292.2 (A), D314.2 (A), D338.2 (A), D360.2 (A), D369.1 (K), D370.1 (K), D371.1 (K), D372.1 (K), D373.1 (K), D374.1 (K), D375.1 (K), D376.1 (K), D377.1 (K), D378.1 (K), D379.1 (K), D380.1 (K), D381.1 (K), D382.1 (K), D383.1 (K), D384.1 (K), D385.1 (K), D386.1 (K), D387.1 (K), D388.1 (K), D389.1 (K), D390.1 (K), D391.1 (K), D406.2 (A), D429.2 (A), D452.2 (A), D475.2 (A), D498.2 (A), D521.2 (A), J1.16
/P17: D17.2 (A), D39.2 (A), D63.2 (A), D85.2 (A), D109.2 (A), D131.2 (A), D155.2 (A), D177.2 (A), D201.2 (A), D223.2 (A), D247.2 (A), D269.2 (A), D293.2 (A), D315.2 (A), D323.1 (K), D324.1 (K), D325.1 (K), D326.1 (K), D327.1 (K), D328.1 (K), D329.1 (K), D330.1 (K), D331.1 (K), D332.1 (K), D333.1 (K), D334.1 (K), D335.1 (K), D336.1 (K), D337.1 (K), D338.1 (K), D339.1 (K), D340.1 (K), D341.1 (K), D342.1 (K), D343.1 (K), D344.1 (K), D345.1 (K), D361.2 (A), D384.2 (A), D407.2 (A), D430.2 (A), D453.2 (A), D476.2 (A), D499.2 (A), D522.2 (A), J1.17
/P18: D18.2 (A), D40.2 (A), D64.2 (A), D86.2 (A), D110.2 (A), D132.2 (A), D156.2 (A), D178.2 (A), D202.2 (A), D224.2 (A), D248.2 (A), D270.2 (A), D277.1 (K), D278.1 (K), D279.1 (K), D280.1 (K), D281.1 (K), D282.1 (K), D283.1 (K), D284.1 (K), D285.1 (K), D286.1 (K), D287.1 (K), D288.1 (K), D289.1 (K), D290.1 (K), D291.1 (K), D292.1 (K), D293.1 (K), D294.1 (K), D295.1 (K), D296.1 (K), D297.1 (K), D298.1 (K), D299.1 (K), D316.2 (A), D339.2 (A), D362.2 (A), D385.2 (A), D408.2 (A), D431.2 (A), D454.2 (A), D477.2 (A), D500.2 (A), D523.2 (A), J1.18
/P19: D19.2 (A), D41.2 (A), D65.2 (A), D87.2 (A), D111.2 (A), D133.2 (A), D157.2 (A), D179.2 (A), D203.2 (A), D225.2 (A), D231.1 (K), D232.1 (K), D233.1 (K), D234.1 (K), D235.1 (K), D236.1 (K), D237.1 (K), D238.1 (K), D239.1 (K), D240.1 (K), D241.1 (K), D242.1 (K), D243.1 (K), D244.1 (K), D245.1 (K), D246.1 (K), D247.1 (K), D248.1 (K), D249.1 (K), D250.1 (K), D251.1 (K), D252.1 (K), D253.1 (K), D271.2 (A), D294.2 (A), D317.2 (A), D340.2 (A), D363.2 (A), D386.2 (A), D409.2 (A), D432.2 (A), D455.2 (A), D478.2 (A), D501.2 (A), D524.2 (A), J1.19
/P20: D20.2 (A), D42.2 (A), D66.2 (A), D88.2 (A), D112.2 (A), D134.2 (A), D158.2 (A), D180.2 (A), D185.1 (K), D186.1 (K), D187.1 (K), D188.1 (K), D189.1 (K), D190.1 (K), D191.1 (K), D192.1 (K), D193.1 (K), D194.1 (K), D195.1 (K), D196.1 (K), D197.1 (K), D198.1 (K), D199.1 (K), D200.1 (K), D201.1 (K), D202.1 (K), D203.1 (K), D204.1 (K), D205.1 (K), D206.1 (K), D207.1 (K), D226.2 (A), D249.2 (A), D272.2 (A), D295.2 (A), D318.2 (A), D341.2 (A), D364.2 (A), D387.2 (A), D410.2 (A), D433.2 (A), D456.2 (A), D479.2 (A), D502.2 (A), D525.2 (A), J1.20
/P21: D21.2 (A), D43.2 (A), D67.2 (A), D89.2 (A), D113.2 (A), D135.2 (A), D139.1 (K), D140.1 (K), D141.1 (K), D142.1 (K), D143.1 (K), D144.1 (K), D145.1 (K), D146.1 (K), D147.1 (K), D148.1 (K), D149.1 (K), D150.1 (K), D151.1 (K), D152.1 (K), D153.1 (K), D154.1 (K), D155.1 (K), D156.1 (K), D157.1 (K), D158.1 (K), D159.1 (K), D160.1 (K), D161.1 (K), D181.2 (A), D204.2 (A), D227.2 (A), D250.2 (A), D273.2 (A), D296.2 (A), D319.2 (A), D342.2 (A), D365.2 (A), D388.2 (A), D411.2 (A), D434.2 (A), D457.2 (A), D480.2 (A), D503.2 (A), D526.2 (A), J1.21
/P22: D22.2 (A), D44.2 (A), D68.2 (A), D90.2 (A), D93.1 (K), D94.1 (K), D95.1 (K), D96.1 (K), D97.1 (K), D98.1 (K), D99.1 (K), D100.1 (K), D101.1 (K), D102.1 (K), D103.1 (K), D104.1 (K), D105.1 (K), D106.1 (K), D107.1 (K), D108.1 (K), D109.1 (K), D110.1 (K), D111.1 (K), D112.1 (K), D113.1 (K), D114.1 (K), D115.1 (K), D136.2 (A), D159.2 (A), D182.2 (A), D205.2 (A), D228.2 (A), D251.2 (A), D274.2 (A), D297.2 (A), D320.2 (A), D343.2 (A), D366.2 (A), D389.2 (A), D412.2 (A), D435.2 (A), D458.2 (A), D481.2 (A), D504.2 (A), D527.2 (A), J1.22
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

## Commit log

2025-02-21 add kicad project
    [led_mapper_850.kicad_pcb, led_mapper_850.kicad_sch]
2025-02-21 add kicad practice project
    [kicad_practice.kicad_pcb, kicad_practice.kicad_sch]
2025-02-21 run ERC & fix connections
    [led_mapper_850.kicad_sch]
2025-02-21 associate footprints
    [led_mapper_850.kicad_sch]
2025-02-21 fix mistakes on diagonal
    [led_mapper_850.kicad_sch]
2025-02-21 load schematic into pcb
    [led_mapper_850.kicad_pcb]
2025-02-21 arrange schematic to match array geometry
    [led_mapper_850.kicad_sch]
2025-02-21 fix horizontal connections
    [led_mapper_850.kicad_sch]
2025-02-21 remove old file
    [led_mapper_850.kicad_sch]
2025-02-21 copy/flip/rotate shenanigans to organise refdes into rows
    after diagonals are collapsed left-right (such that there are 12 rows), references are simply listed left to right then top to bottom
    [led_mapper_850.kicad_pcb, led_mapper_850.kicad_sch]
2025-02-21 fix missing wire & references
    [led_mapper_850.kicad_sch]
2025-02-21 add spacing constants
    [pixel_loc_analysis.xlsx]
2025-02-22 lay out network from pcb positions
    [led_mapper_850.kicad_pcb, led_mapper_850.kicad_sch]
2025-02-25 fix wire disconnect
    [led_mapper_850.kicad_sch]
2025-02-25 update pcb from schematic
    [led_mapper_850.kicad_pcb]
2025-02-25 place vias
    [led_mapper_850.kicad_pcb]
2025-02-26 wire most traces
    [led_mapper_850.kicad_pcb]
2025-02-26 update remote
    [led_mapper_850.kicad_pcb]
2025-02-26 complete wiring after rotating leds
    [led_mapper_850.kicad_pcb]
2025-02-26 split into four networks
    [led_mapper_850.kicad_sch, untitled.kicad_sch]
2025-02-27 sync pcb
2025-03-01 first complete wiring - some DRC errors
2025-03-03 v0 compete - all DRC passing (except silkscreen)
2025-03-03 rename single net schematic
    [led_mapper_850.kicad_sch, single_net.kicad_sch]
2025-03-03 add multiplexer
    [led_CCAT_multiplexer.kicad_pcb, led_CCAT_multiplexer.sch]
2025-03-03 add 6 connectors to multiplexer
    [led_CCAT_multiplexer.kicad_pcb, led_CCAT_multiplexer.kicad_sch]
2025-03-03 clean up front connector wires
    [single_net.kicad_sch]
2025-03-03 more wire cleanup
2025-03-04 add collimator dxf for comparison
    [collimator_rhombus_850.dxf]
2025-03-04 remove practice project
    [kicad_practice.kicad_pcb, kicad_practice.kicad_sch]
2025-03-04 restore copper zones
    [led_CCAT_multiplexer.kicad_pcb]
2025-03-05 refactor directories
    [collimator_rhombus_850.dxf, led_mapper_850.kicad_sch, single_net.kicad_sch]
2025-03-05 remove sch
    [single_net.kicad_sch]
2025-03-06 use single connector
    [led_mapper_850.kicad_sch, single_net.kicad_sch]
2025-03-06 start placing & routing
    [led_mapper_850.kicad_sch, single_net_reverse_cols.kicad_sch]
2025-03-06 rework row vias & front row shorts
    [single_net.kicad_sch, single_net_reverse_cols.kicad_sch]
2025-03-07 automate in2 connector cables
2025-03-07 fix extra track
2025-03-08 add v2 gerber
2025-03-08 add led part number - XINGLIGHT Red 0201
    [led_mapper_850.kicad_sch, single_net.kicad_sch, single_net_reverse_cols.kicad_sch]
2025-03-08 add fabrication outputs for previewing PCBA quote
    [led_mapper_850.kicad_sch, single_net.kicad_sch, single_net_reverse_cols.kicad_sch]
2025-03-10 add collimator CAD files
    [280_GHz_Si_Array_Final_Backplate_08112022.SLDPRT, 280_GHz_Si_Array_Final_Backplate_202502.SLDPRT, 280_ghz_collimator.SLDPRT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]
2025-03-10 update pcb edge cuts to be 3mm on top & left
2025-03-11 align collimator & pcb model in CAD
    [led_mapper_850.step]
2025-03-11 tighten connector position
2025-03-12 fix critical schematic error - wrong pins
    [single_net.kicad_sch, single_net_reverse_cols.kicad_sch]
2025-03-12 sync cad file
2025-03-12 rebuild board layout to fix net errors
2025-03-12 fix network issues (pin name mismatch)
    [single_net_reverse_cols.kicad_sch]
2025-03-12 set hole diameter to 0.9mm
2025-03-13 build exact board outline
    [board_outline.DXF, led_mapper_850_v3.step]
2025-03-14 add mirrored rhombus
    [board_outline._2mmholes.DXF, led_mapper_850.kicad_sch, led_mapper_850_mirrored.kicad_pcb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]
2025-03-14 mirror rhombus
    [board_outline._2mmholes.DXF, led_mapper_850.kicad_sch, led_mapper_850_mirrored.kicad_sch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]
2025-03-14 update board outline
    [board_outline_2mmholes_mirrored.DXF, board_outline_2mmholes_v4.DXF]
2025-03-14 complete assembly
    [led_mapper_850_mirrored.step, led_mapper_850_v5.step]
2025-03-17 clean up assembly
    [led_mapper_850_mirrored.step, led_mapper_850_v5.step]
2025-03-19 sync local work
    [board_outline_2mmholes_mirrored_v2.DXF, led_mapper_850_mirrored_v2.step, led_mapper_850_v6.step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]
2025-03-21 fix anode cathode mixup and get pin arrays for all networks
2025-03-26 Sync changes: update holes to 2.2mm, change footprint to match datasheet
    [board_outline_2.2mmholes.DXF, board_outline_2.2mmholes_mirrored.DXF, single_net.kicad_sch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]
2025-03-26 missed file - schematic
    [single_net.kicad_sch]
2025-03-26 add production outputs
    [led_mapper_850-B_Cu.gbl, led_mapper_850-B_Mask.gbs, led_mapper_850-B_Paste.gbp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]
2025-03-26 add csv files
    [bom.csv, designators.csv, pixel_locs.csv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]
2025-04-15 add collimator dxf
    [850_ghz_collimator_topface.DXF]
